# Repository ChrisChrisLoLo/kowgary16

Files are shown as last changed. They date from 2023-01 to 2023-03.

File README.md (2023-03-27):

# kowgary16

A low profile, ultra-portable companion piece to the bancouver40



# Note
This keypad works 17x17 choc keycaps, like the Chosfox CFX keycaps. This will _not_ fit with MBK or kailh choc keycaps.

# Status
This macropad is confirmed to work!

# BOM
BOM for pcb included in the `pcb` folder. You will additionally need 4 rubber feet, the aluminum CNC case, as well as 4x 4mm M2 screws

# Acknowledgements
Thank you [PCBWay](https://www.pcbway.com/) for sponsoring this project! It continues to impress me that I can use their services to make consumer grade enclosures. I've been going with their bead blasted anodized aluminum offerings with the premium finish option selected, and am continually thrilled by the quality. I only had to pay $48 USD to get the kowgary case manufactured, which is a fantastic price for a premium feeling macropad!

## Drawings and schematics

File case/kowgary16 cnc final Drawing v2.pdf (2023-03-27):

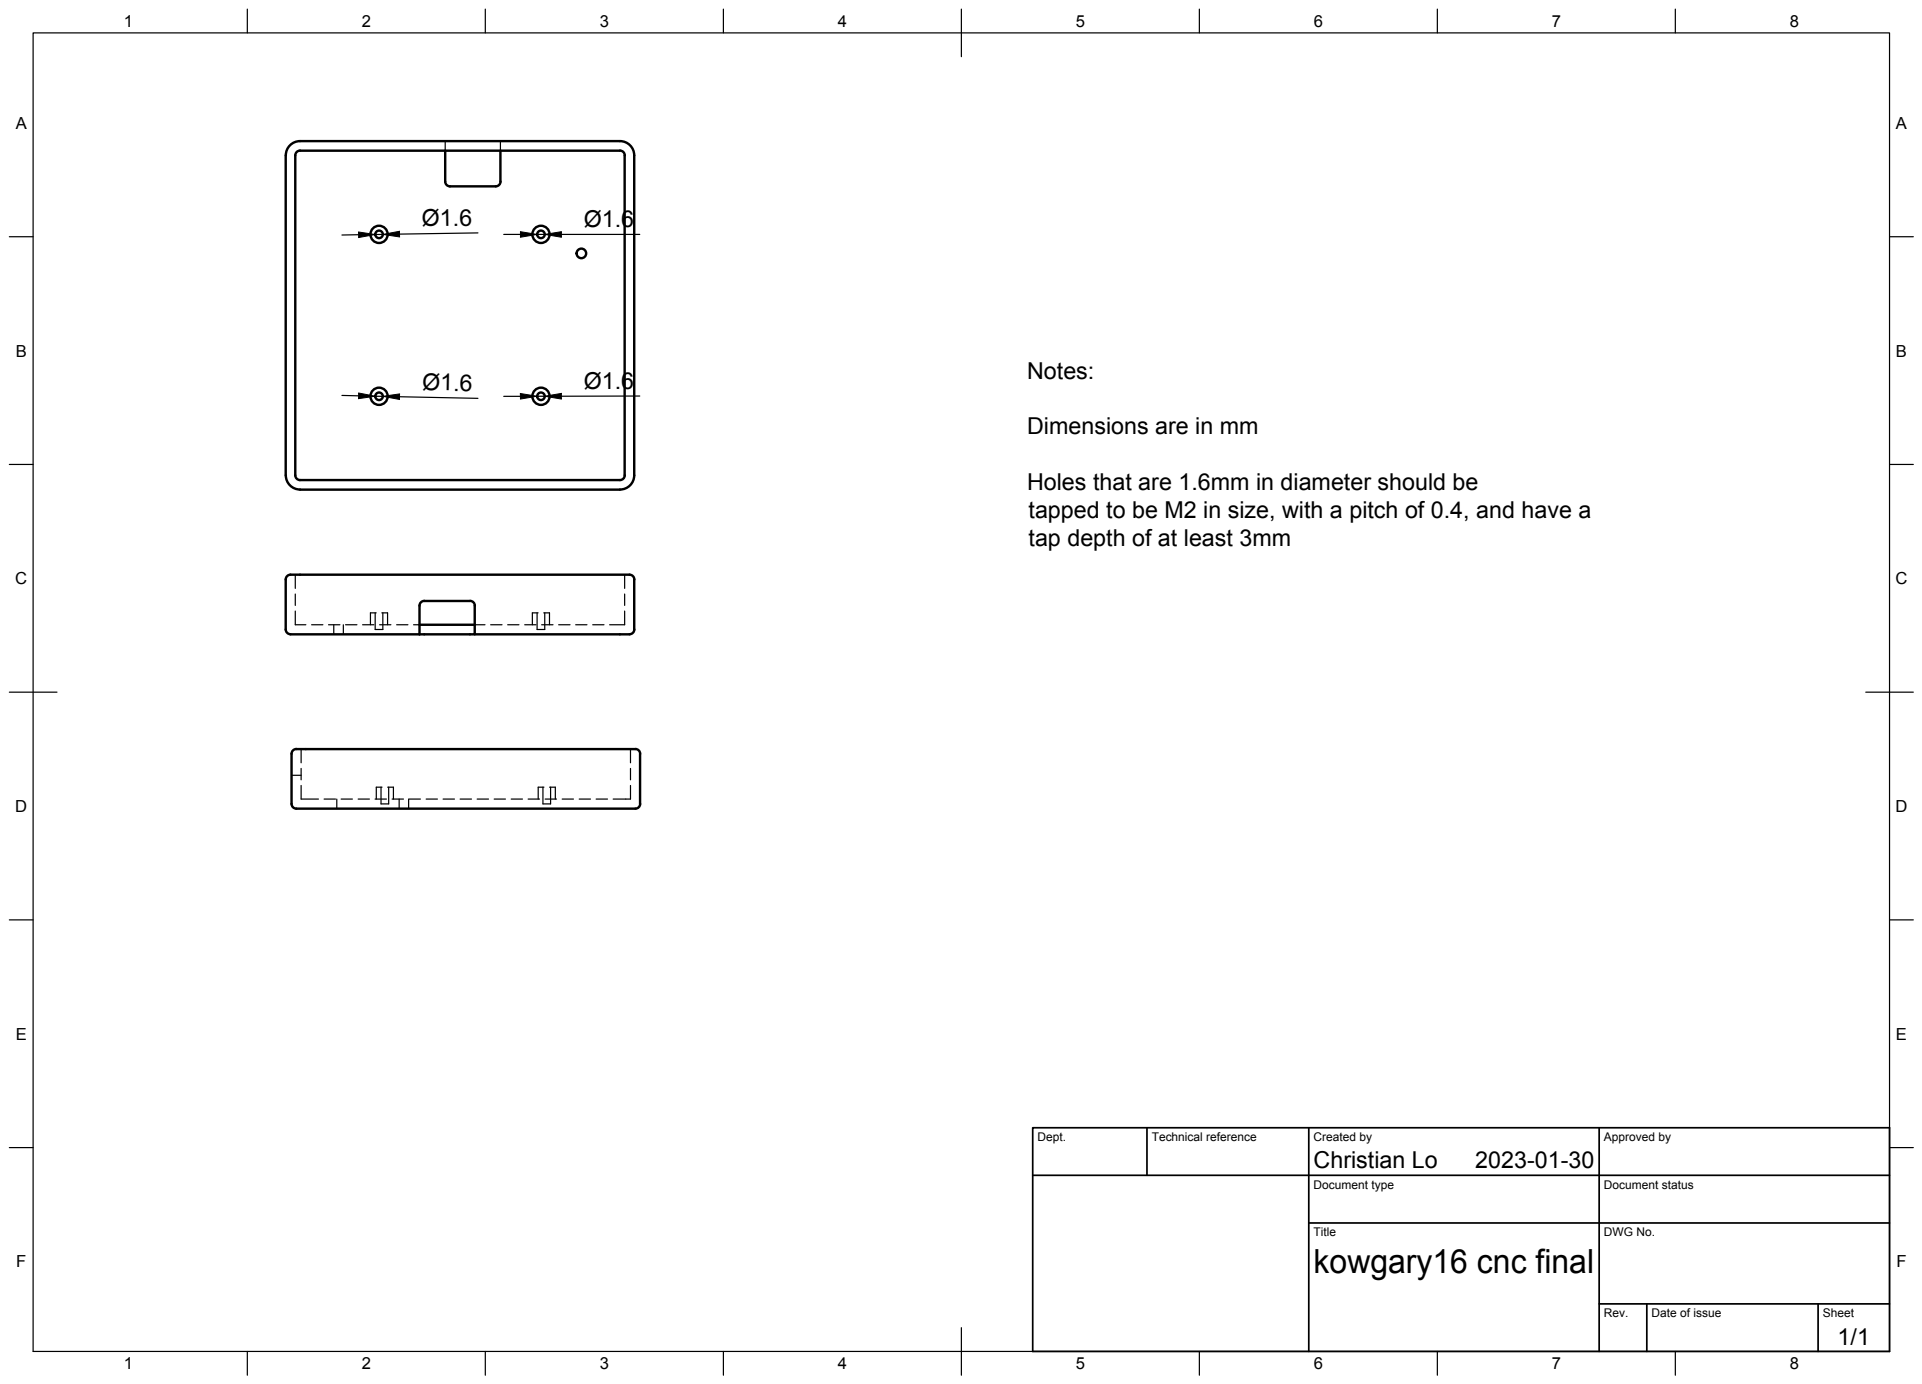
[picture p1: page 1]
Title; DWG No.; Rev.; Date of issue; Sheet; kowgary16 cnc final

Dimensions are in mm

Holes that are 1.6mm in diameter should be
tapped to be M2 in size, with a pitch of 0.4, and have a
tap depth of at least 3mm

Dept. | Technical reference | Created by Christian Lo 2023-01-30 | Approved by

Document type | Document status

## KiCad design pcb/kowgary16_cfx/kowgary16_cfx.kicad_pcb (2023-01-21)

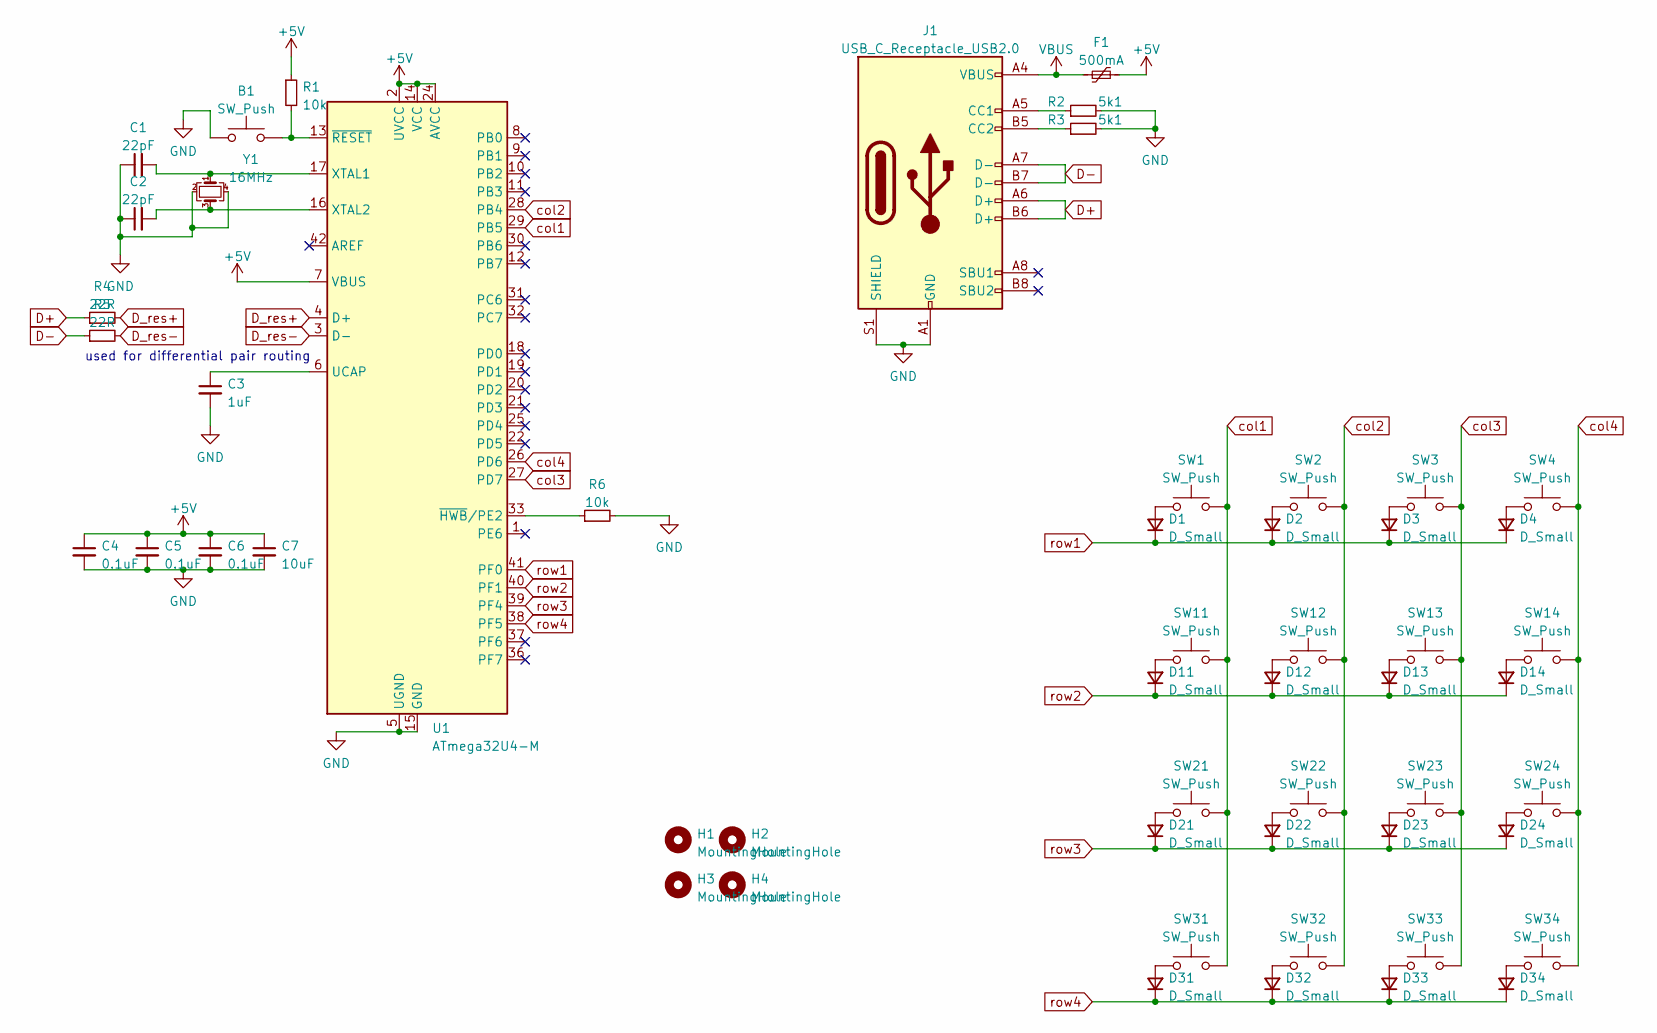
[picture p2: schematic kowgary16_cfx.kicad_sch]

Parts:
B1: SW_Push; SW_SPST_SKQG_WithoutStem
C1, C2: 22pF; C_0402_1005Metric
C3: 1uF; C_0402_1005Metric
C4, C5, C6: 0.1uF; C_0402_1005Metric
C7: 10uF; C_0402_1005Metric
D1, D2, D3, D4, D11, D12, D13, D14, D21, D22, D23, D24, D31, D32, D33, D34: D_Small; D_SOD-323
F1: 500mA; Fuse_1206_3216Metric
H1, H2, H3, H4: MountingHole; MountingHole_2.2mm_M2_ISO7380
J1: USB_C_Receptacle_USB2.0; USB_C_Receptacle_XKB_U262-16XN-4BVC11
R1, R6: 10k; R_0402_1005Metric
R2, R3: 5k1; R_0402_1005Metric
R4, R5: 22R; R_0402_1005Metric
SW1, SW2, SW3, SW4, SW11, SW12, SW13, SW14, SW21, SW22, SW23, SW24, SW31, SW32, SW33, SW34: SW_Push; Kailh_socket_PG1350
U1: ATmega32U4-M; QFN-44-1EP_7x7mm_P0.5mm_EP5.2x5.2mm
Y1: 16MHz; Crystal_SMD_3225-4Pin_3.2x2.5mm

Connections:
+5V: C4.1, C5.1, C6.1, C7.1, F1.2, R1.1, U1.2 (UVCC), U1.7 (VBUS), U1.14 (VCC), U1.24 (AVCC), U1.34 (VCC), U1.44 (AVCC)
D+: J1.A6 (D+), J1.B6 (D+), R4.1
D-: J1.A7 (D-), J1.B7 (D-), R5.1
D_res+: R4.2, U1.4 (D+)
D_res-: R5.2, U1.3 (D-)
GND: B1.1, C1.1, C2.1, C3.2, C4.2, C5.2, C6.2, C7.2, J1.A1 (GND), J1.A12 (GND), J1.B1 (GND), J1.B12 (GND), J1.S1 (SHIELD), R2.2, R3.2, R6.2, U1.5 (UGND), U1.15 (GND), U1.23 (GND), U1.35 (GND), U1.43 (GND), U1.45 (GND), Y1.2, Y1.4
unnamed: B1.2, R1.2, U1.13 (~RESET)
unnamed: C1.2, U1.17 (XTAL1), Y1.1
unnamed: C2.2, U1.16 (XTAL2), Y1.3
unnamed: C3.1, U1.6 (UCAP)
unnamed: D1.2 (A), SW1.1
unnamed: D2.2 (A), SW2.1
unnamed: D3.2 (A), SW3.1
unnamed: D4.2 (A), SW4.1
unnamed: D11.2 (A), SW11.1
unnamed: D12.2 (A), SW12.1
unnamed: D13.2 (A), SW13.1
unnamed: D14.2 (A), SW14.1
unnamed: D21.2 (A), SW21.1
unnamed: D22.2 (A), SW22.1
unnamed: D23.2 (A), SW23.1
unnamed: D24.2 (A), SW24.1
unnamed: D31.2 (A), SW31.1
unnamed: D32.2 (A), SW32.1
unnamed: D33.2 (A), SW33.1
unnamed: D34.2 (A), SW34.1
unnamed: J1.A5 (CC1), R2.1
unnamed: J1.B5 (CC2), R3.1
unnamed: R6.1, U1.33 (~HWB/PE2)
VBUS: F1.1, J1.A4 (VBUS), J1.A9 (VBUS), J1.B4 (VBUS), J1.B9 (VBUS)
col1: SW1.2, SW11.2, SW21.2, SW31.2, U1.29 (PB5)
col2: SW2.2, SW12.2, SW22.2, SW32.2, U1.28 (PB4)
col3: SW3.2, SW13.2, SW23.2, SW33.2, U1.27 (PD7)
col4: SW4.2, SW14.2, SW24.2, SW34.2, U1.26 (PD6)
row1: D1.1 (K), D2.1 (K), D3.1 (K), D4.1 (K), U1.41 (PF0)
row2: D11.1 (K), D12.1 (K), D13.1 (K), D14.1 (K), U1.40 (PF1)
row3: D21.1 (K), D22.1 (K), D23.1 (K), D24.1 (K), U1.39 (PF4)
row4: D31.1 (K), D32.1 (K), D33.1 (K), D34.1 (K), U1.38 (PF5)

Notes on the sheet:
used for differential pair routing

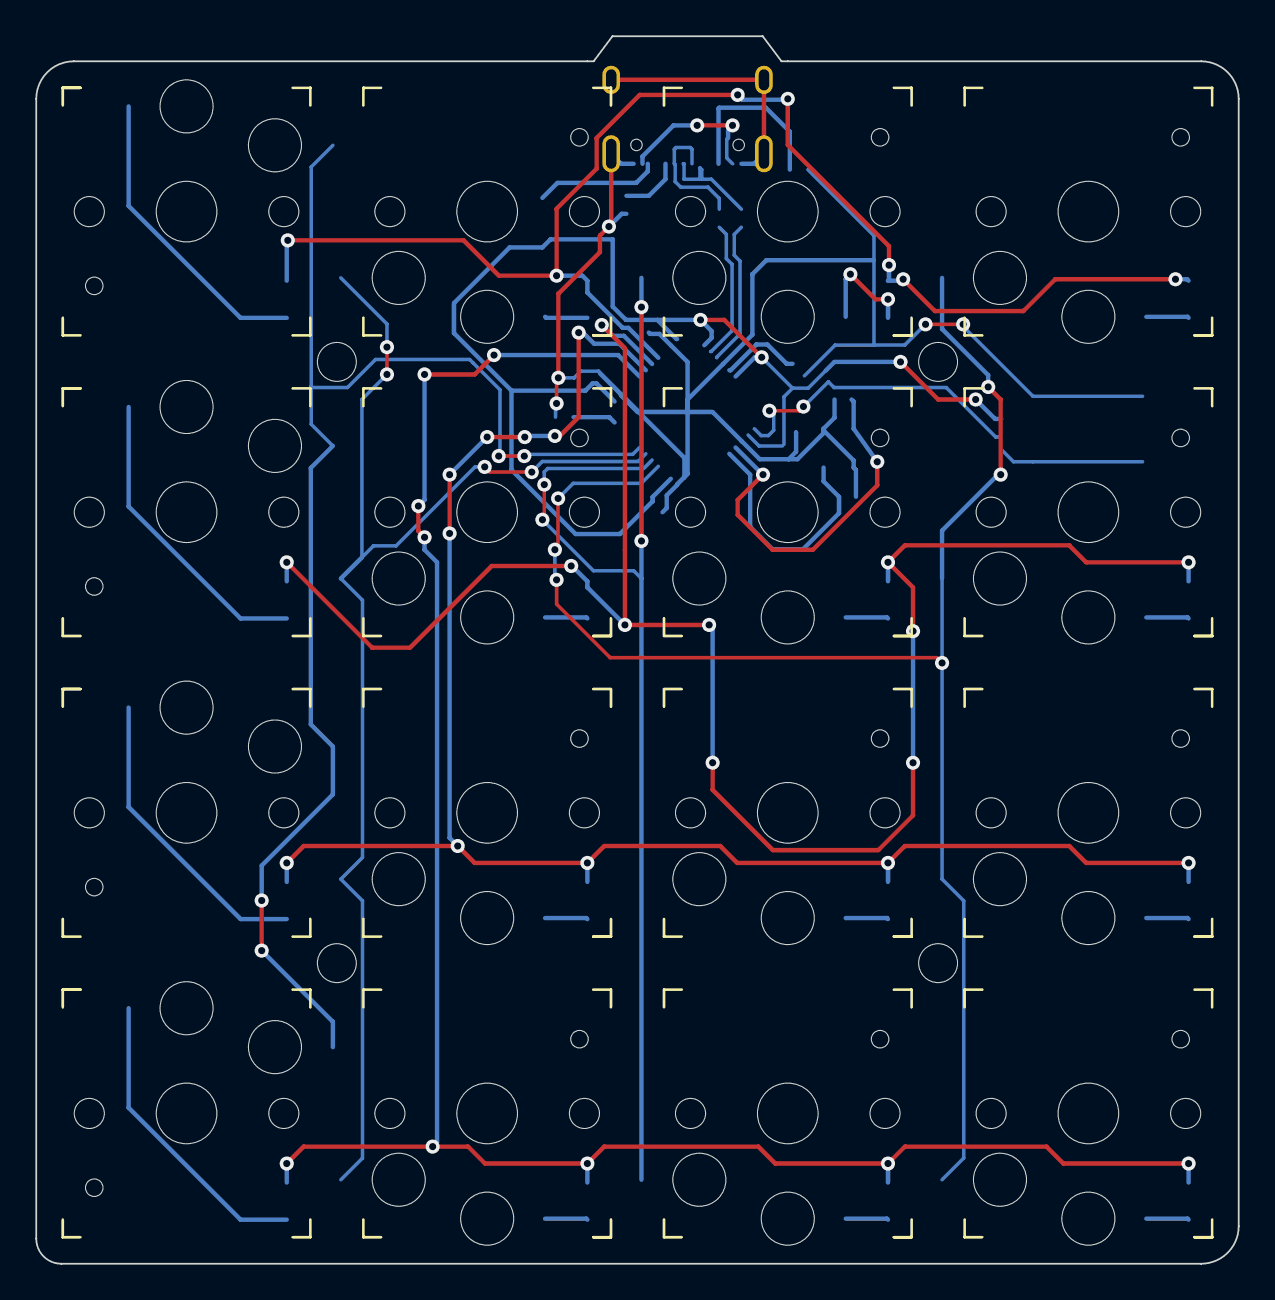
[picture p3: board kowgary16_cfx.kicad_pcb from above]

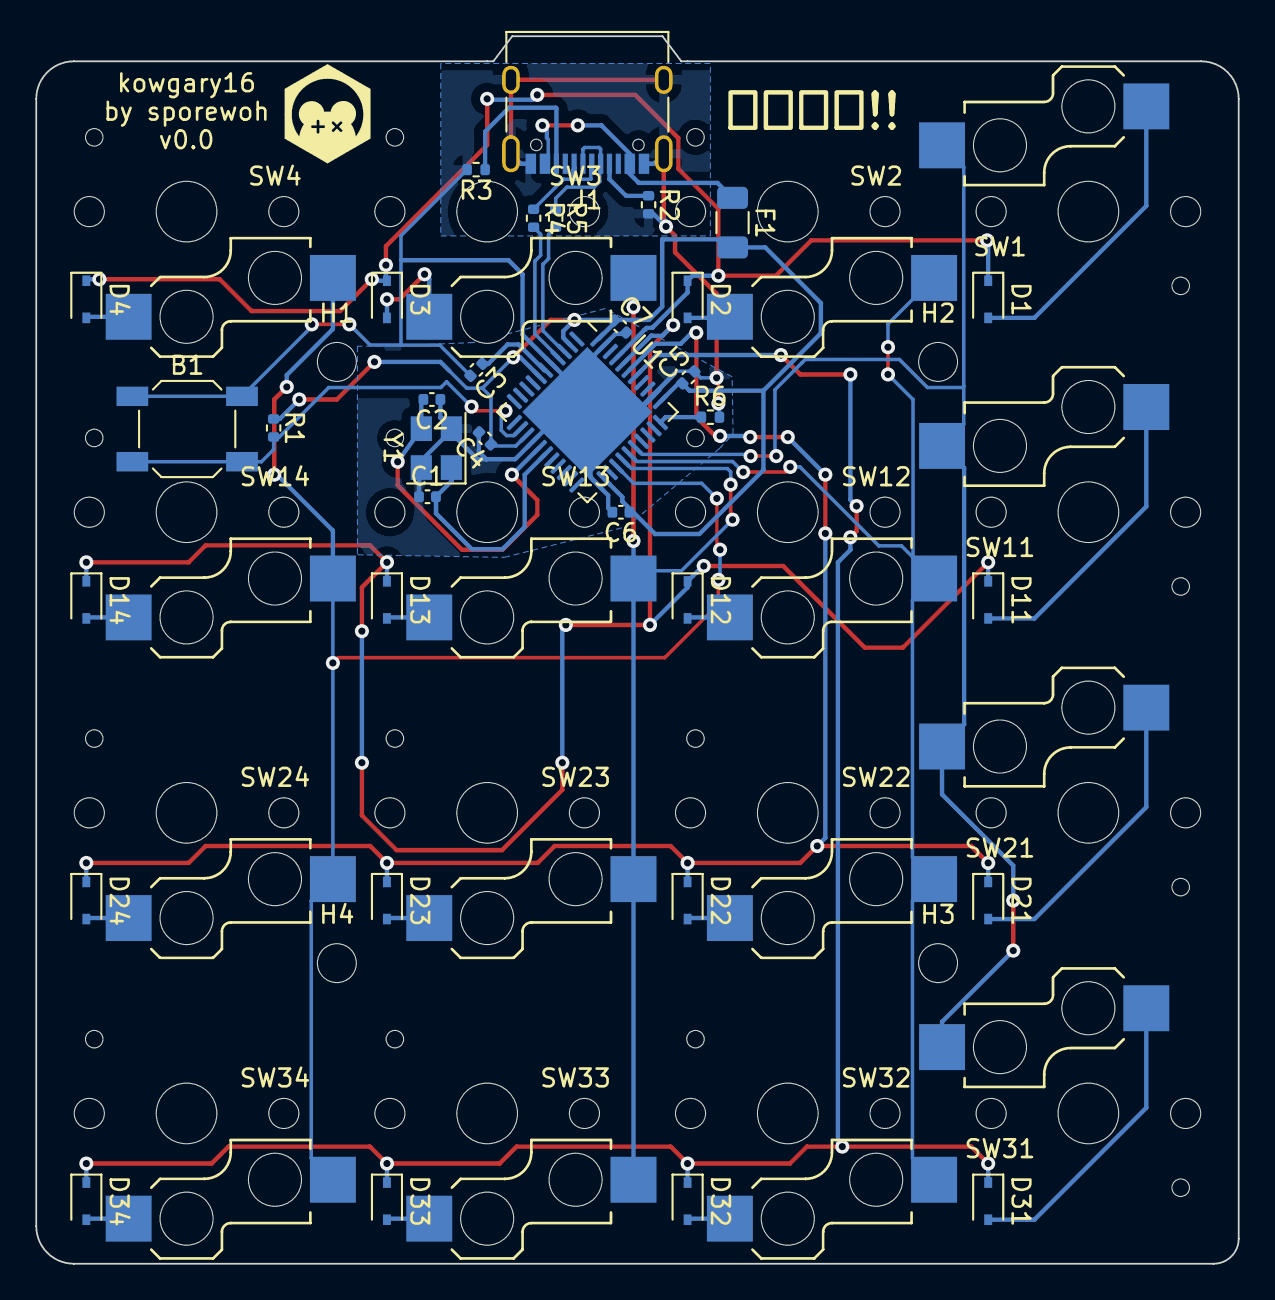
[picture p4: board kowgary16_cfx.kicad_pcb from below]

Board: 2 copper layers, 68.0 x 69.4 mm, 54 parts (38 on the bottom side), 38 nets.
